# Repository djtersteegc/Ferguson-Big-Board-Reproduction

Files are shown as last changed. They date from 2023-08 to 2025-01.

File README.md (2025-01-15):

# Ferguson Big Board Reproduction

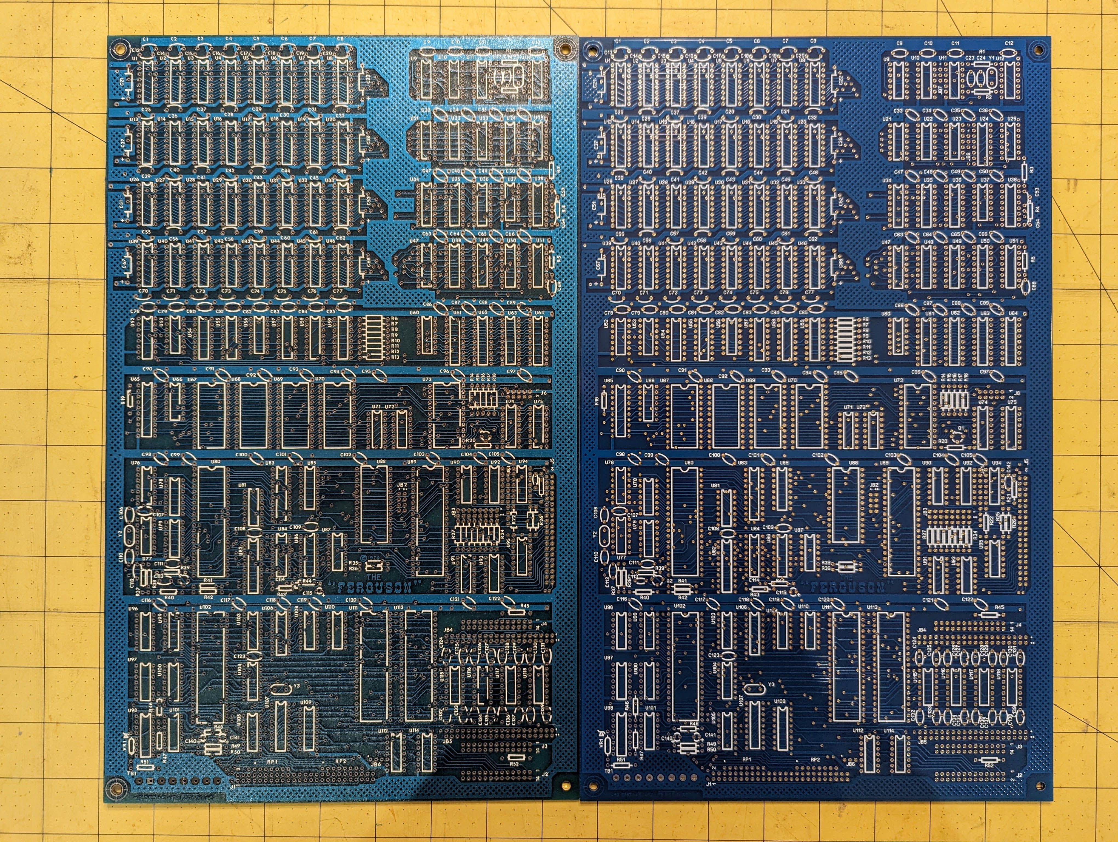
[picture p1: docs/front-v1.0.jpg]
front


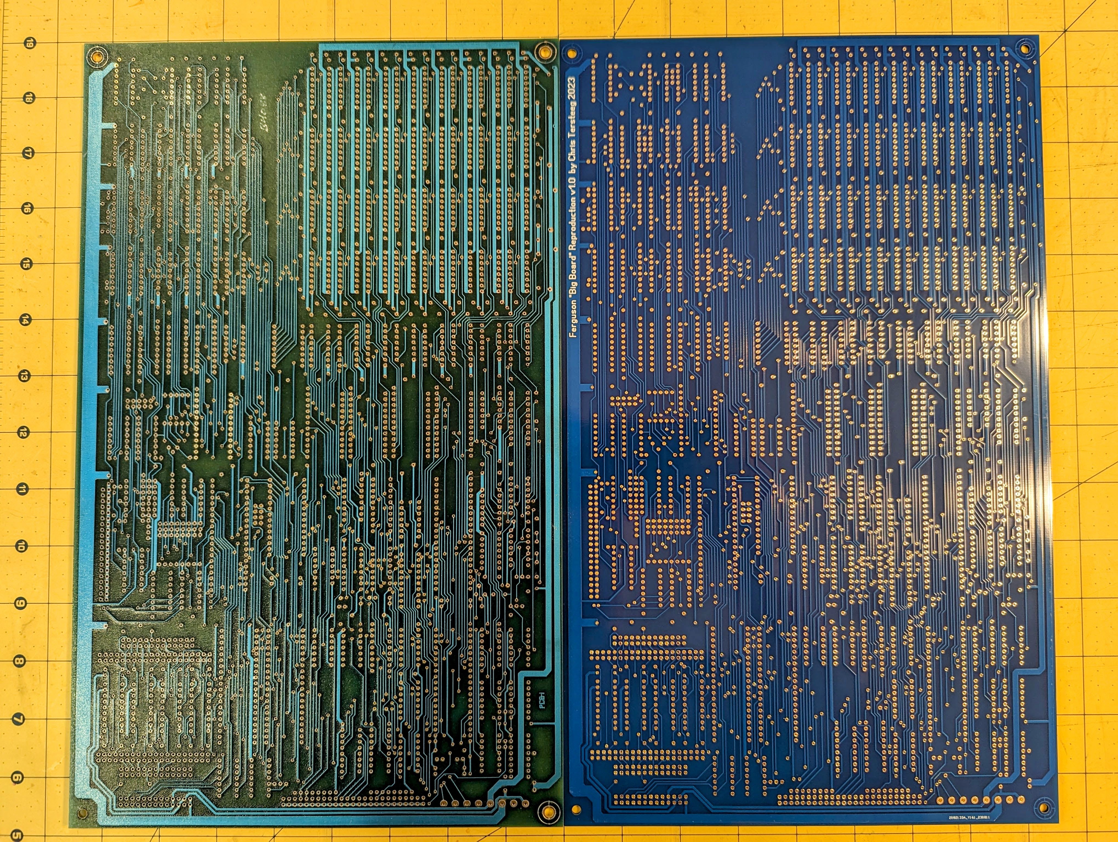
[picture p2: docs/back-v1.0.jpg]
back


Original is on the left above, the repoduction is on the right. Redraw in Sprint Layout from scans of an unpopulated board, serial number B4088.  Project discussion thread on VCF is at https://forum.vcfed.org/index.php?threads/recreating-the-ferguson-big-board.68349/ 

Mostly original with the following changes present on v1.0 and v1.1 boards:

Silkscreen of U52 corrected from a DIP-16 to DIP-14 socket.

Silkscreen reference Q1 added

Silkscreen reference Q2 added

Silkscreen reference R21 added

Silkscreen reference C142 added

Added missing vias for the top two memory bank -5V traces

Pin 14 silkscreen reference on J2 (keyboard connector) corrected to read pin 2

Jumper JB7 added to switch line character count between 97 and 128.  Strap middle pin to top pin to connect U11 pin 3 to +5V for 128 counts. Strap middle pin to bottom pin to connect U11 pin 3 to U10 pin 2 for 97 counts. *Micro Cornucopia, Number 10, February 1983, page 32*

Jumper JB8 added to switch between 7 and 8 dot character widths. Strap middle pin to top pin to connect U24 pin 3 to +5V for 7 dots. Strap middle pin to bottom pin to connect U24 pin 3 to GND for 8 dots. *Micro Cornucopia, Number 10, February 1983, page 32*

### Original Schematic Errata

**Sheet 4 - Floppy, Keyboard PIO, CTC**

IORQ input on U111 (PIO) should be pin 36, not pin 34

Connector J1-6 (Low Current) connects to resistor network pin RN1-2, not RN1-3.

Resistor networks RN1 and RN2 are labeled RP1 and RP2 respectively on the PCB silkscreen

The output from U87 pin 4 that controls the two 74LS242 buffers, U99 and U100, does not go though U103 and instead hooks directly to the 74LS242 chips.  This makes sense since you need a high signal to the buffers to read data from the FD1771 which U87 (NOR) outputs when both 1771CS and RDB are asserted active low.

##### Sheet 5 - GP PIO/SIO

BAUDA and BAUDB are reversed, U107 (8116) Pin 12 is BAUDB, U107 (8116) Pin 8 is BAUDA

### **V1.0 PCB Errata**

Like the original board, VPP on the Character Set EPROM (U73, pin 21) is unconnected and needs to be wired to +5V (U73, pin 24) for normal operation.

C114 pads have the footprint of vias and no symbol on the silkscreen layer.  Same as the original, but could be improved.

Right pad R40 unconnected, should be connected on bottom copper to the base of Q2 above it.

Top pad of R25 unconnected, should be connected on top copper to top pad of R26.

Pins 4 and 5 at U77 unconnected, should be connected on bottom copper.

Pins 19 and 20 on U65 unconnected, should be connected on bottom copper.

RP2-6 and J1-42 are unconnected, should be connected on bottom copper.

RP1-2 and J1-6 are unconnected, should be connected on top copper.

U81 pin 1 should be connected on top copper to the via immedately to it's right which goes to U84 pin 5. 

U22 pin 8 should be connected to the trace running immediately above it to connect to U9 pin 11 and U25 pin 5.  There is a via under U21by pin 9 that can complete this connection.

U37 pin 6 should be connected to trace running immediately below it to connect to U38 pin 10 and U10 pin 5. A bodge between U37-6 and U38-10 is the most direct.

U35 pin 1 should be connected to the +5V rail immediately above it.

### **V1.1 PCB**

All the V1.0 errata has been fixed and some additional features dicussed below added.  The goal was still to try to maintain a stock appearance from the topside, so the additional frequency selection and power to floppy disk port jumpers are all on the back side of the board.

#### 4 MHz Operation

One of the popular mods was reaplacing the Z80 with Z80A and increasing the frequency from 2.5 MHz to 4 MHz.  There were several ways to do this, but v1.1 implements the ability to easily do the mod discussed in Micro Cornucopia issue #3 (which is what Kaypro also adopted in their designs) with solder jumpers on the back of the board.  No trace cutting or bodge wires needed.

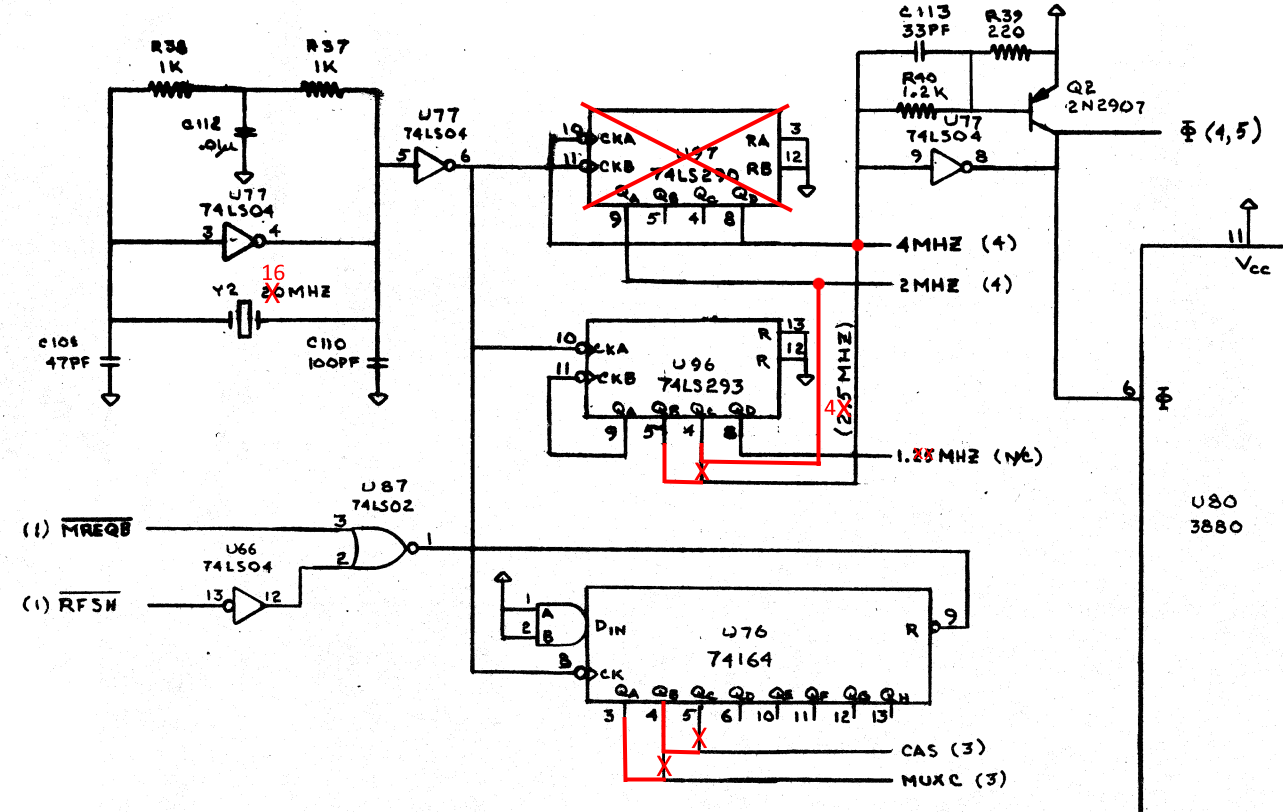
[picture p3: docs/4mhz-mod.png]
4mhz-mod


For stock 2.5 MHZ operation you need to install all the IC's per the BOM and use a 20 MHz crystal for Y2.  Then close the following three solder jumpers.

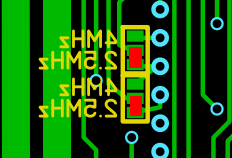
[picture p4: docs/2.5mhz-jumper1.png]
2.5mhz-jumper1


2.5mhz-jumper2

For 4 MHZ operation do NOT install U97 and use a 16 MHz crystal for Y2.  Then close the following five solder jumpers.

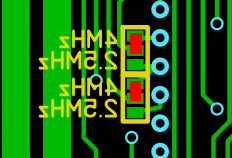
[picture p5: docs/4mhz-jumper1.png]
4mhz-jumper1


4mhz-jumper2

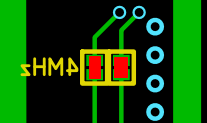
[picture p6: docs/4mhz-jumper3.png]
4mhz-jumper3


#### Fully Compensated Video Output

Another Micro Cornucopia article in issue #14 discussing swapping the 74LS123's in the video output circuit with 74LS221's that are both voltage and temperature compensated in an effort to improve video output jitter.

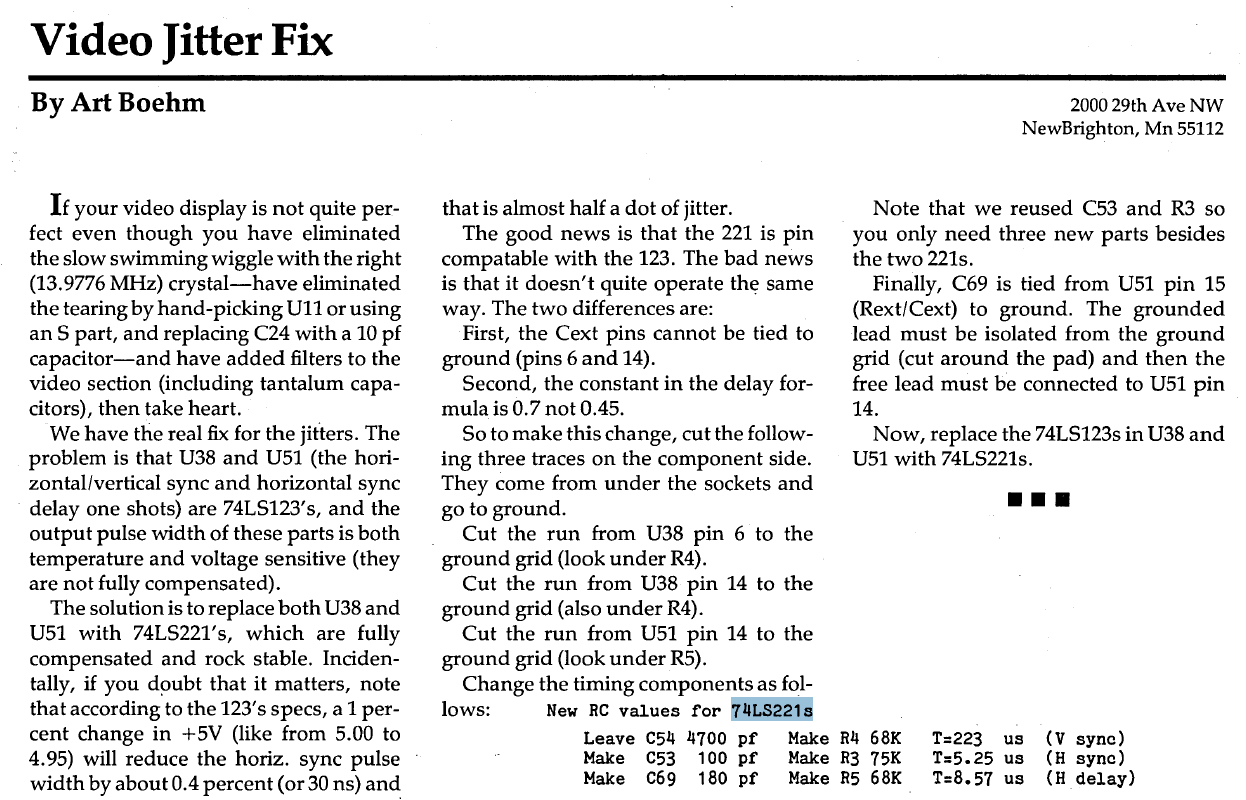
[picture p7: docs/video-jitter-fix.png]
video-jitter-fix


v1.1 already disconnects the appropiate pins on U38 and U51 from ground so all you need to do is use the updated values for C53, C69, R4, R3, and R5.

#### Additional Tantalum Capacitor Locations

Many Micro Cornucopia articles discussed bodging some additional tantalum caps to the video output section to improve quality.  While not labeled on the board to keep it more original looking, there are extra spots now to add them if you want to experiment.  Someone like a 22uF 10V (or higher) cap it probably a good start.

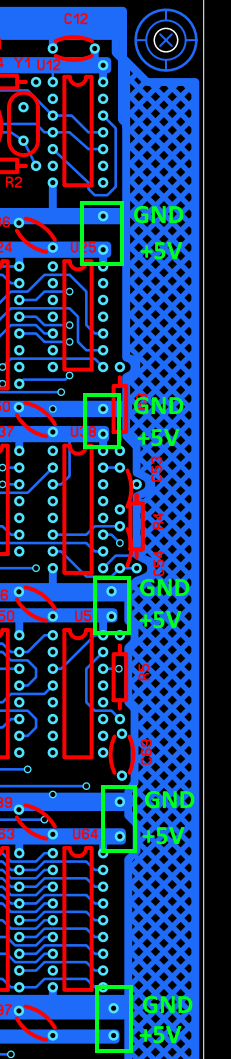
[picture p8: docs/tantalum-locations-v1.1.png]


### Serial Keyboard Adapter

I also created a PS/2 to parallel keyboard adapter PCB that should plug right into the Big Board based on the work shared here, https://forum.vcfed.org/index.php?threads/ferguson-big-board-1-monitor-rom.32705/#post-405189.  It's available at https://github.com/djtersteegc/ferguson-ps2-keyboard-adapter

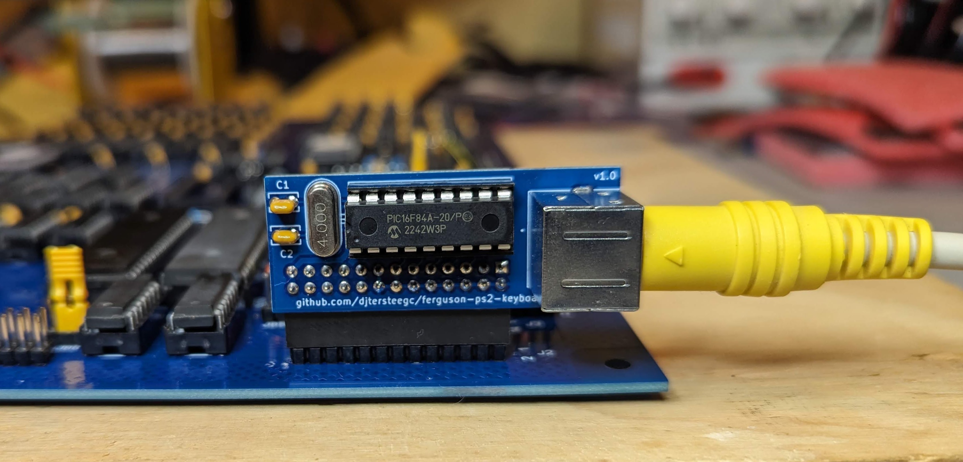
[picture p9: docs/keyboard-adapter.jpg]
keyboard-adapter


Strap JB6 center to right pad to set negative strobe.

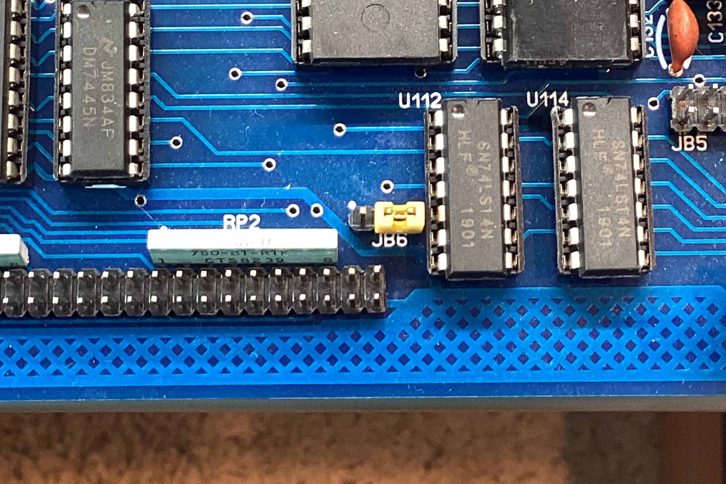
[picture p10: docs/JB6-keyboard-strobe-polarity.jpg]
JB6-keyboard-strobe-polarity


### Power

The manual calls for the following:

+5V at 3 amps

+12V at 0.25 amps

-12V at 0.20 amps

Either a Mean Well RT-50B (5V@4A) or RT-65B (5V@5A) will do the job. I chose the slighty larger RT-65B since it was only a few bucks more. 3D printable case designs for both that also incorporate the reset button are available in the [psu](psu/README.md) directory.

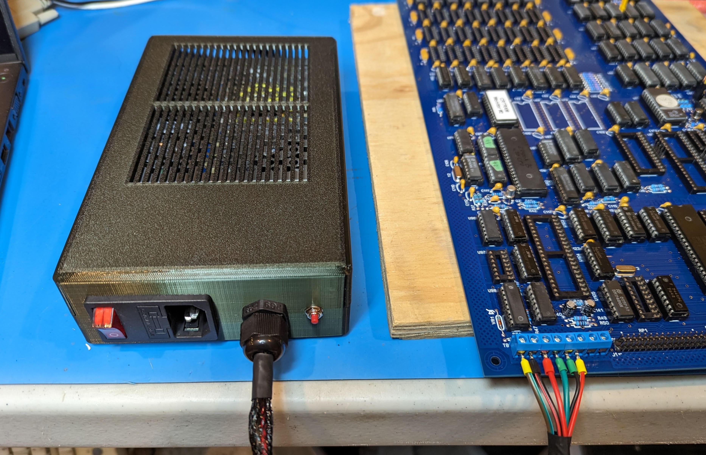
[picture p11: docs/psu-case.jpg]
psu-case


### Composite Video Output

On JB1 connect pins 10 and 11, pins 3 and 4, and pins 5 and 6.

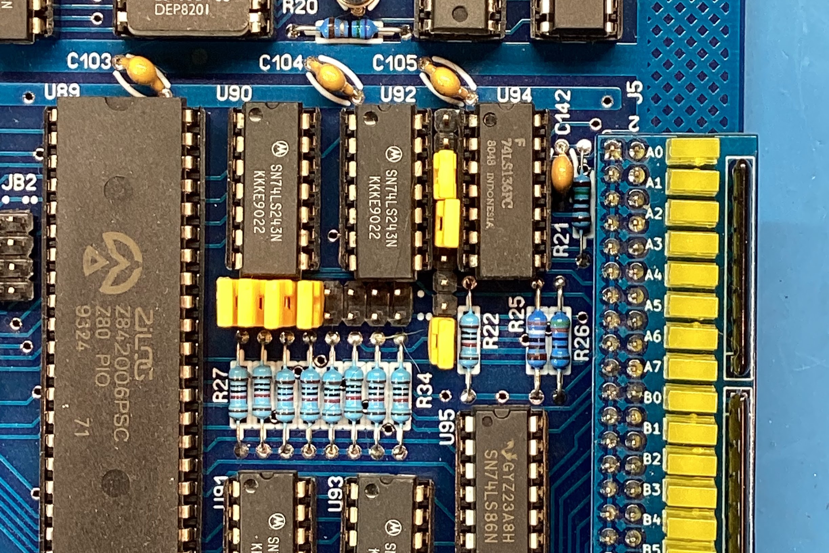
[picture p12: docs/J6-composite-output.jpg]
J6-composite-output


This routes both the v.sync and h.sync signals to the composite output, and inverts the video (white on black). Then build a cable using something like a Dupont two pin 2.54mm connector and connect you ground to pin 9 and signal to pin 10 on connector J6.

If you want to make a fancy composite video adapter PCB, head over to the [composite-video-adapter](composite-video-adapter/README.md) directory.

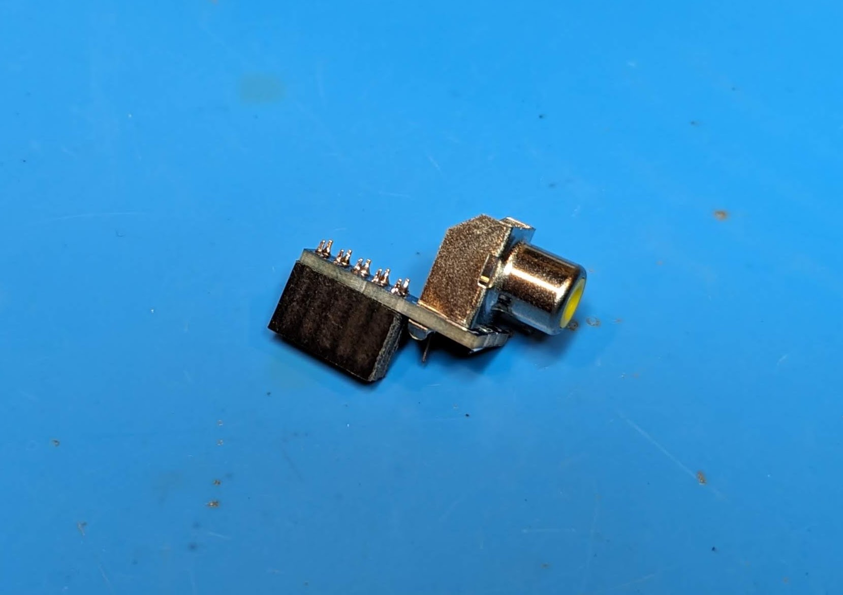
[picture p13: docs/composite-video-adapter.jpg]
composite-video-adapter


Jumper JB7 and JB8 were not on the original boards, but added to implement the following video display options/improvements mentioned in *Micro Cornucopia, Number 10, February 1983, page 32*

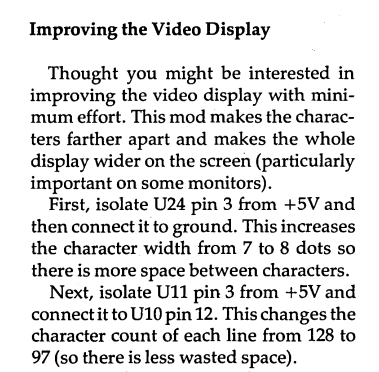
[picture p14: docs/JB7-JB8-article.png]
JB7-JB8-article


Jumper JB7 switches line character count between 97 and 128.  Strap middle pin to top pin to connect U11 pin 3 to +5V for 128 counts. Strap middle pin to bottom pin to connect U11 pin 3 to U10 pin 2 for 97 counts.

Jumper JB8 switches between 7 and 8 dot character widths. Strap middle pin to top pin to connect U24 pin 3 to +5V for 7 dots. Strap middle pin to bottom pin to connect U24 pin 3 to GND for 8 dots.

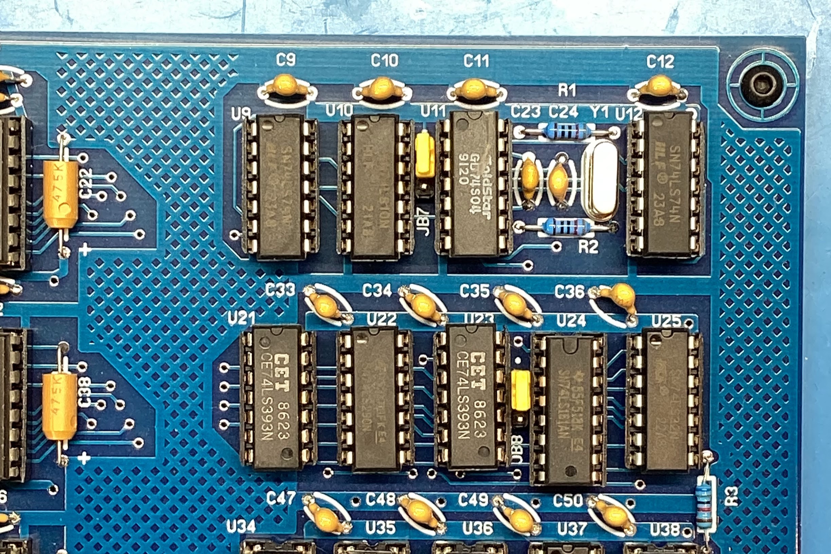
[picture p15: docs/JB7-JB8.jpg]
JB7-JB8


### Serial Terminal

Instead of a keyboard and monitor, you can also operate the BigBoard via a serial termainl connected to the B channel connector J3.  For a DB9 male DTE cable wire accordingly, I used a three pin Dupont connector.  

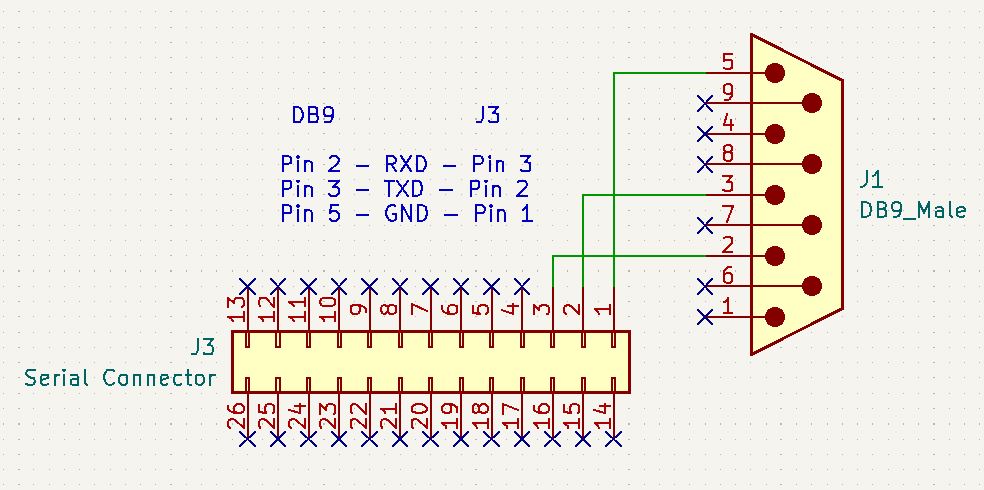
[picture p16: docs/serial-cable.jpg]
serial-cable
  

On JB5 jumper pins 5 and 6, and pins 9 and 10.

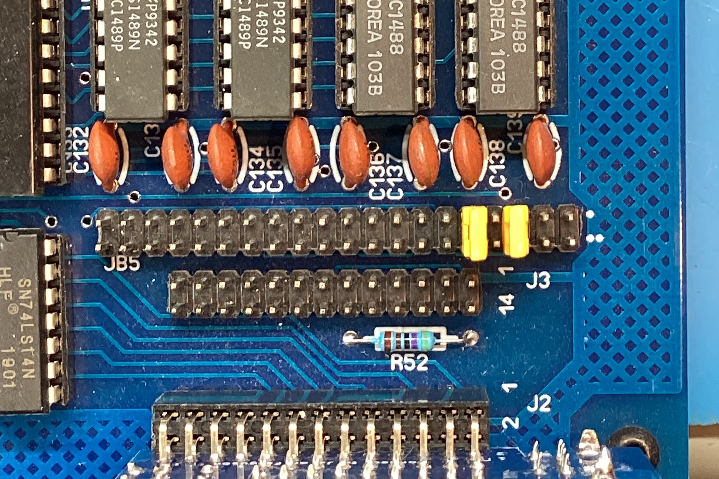
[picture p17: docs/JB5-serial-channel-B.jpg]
JB5-serial-channel-B


You will need to use a null modem cable to connect to your terminal device, or PC USB adapter running something like Terraterm.

The port will autobaud when you hit the return key, up to 19.2K.  I run the terminal set to 19,200 baud, 7 bit, odd parity, 1 stop bits, with no flow control.  When you startup or reset the big board, the first device, keyboard or serial terminal, that sends a return character will become the input and output device for the board.

### Floppy Drive

A number of disk image compatible with a Flash Floppy converted Gotek are available in the [flashfloppy](flashfloppy) directory.  Copy the content of the directoy to a USB stick and make sure you are using an up to date version of the Flash Floppy firmware.

To convert the 50 pin drive connector to a 34 pin floppy drive, you can build the adapter in the [50-to-34-pin-floppy-adapter](50-to-34-pin-floppy-adapter/README.md) directory.

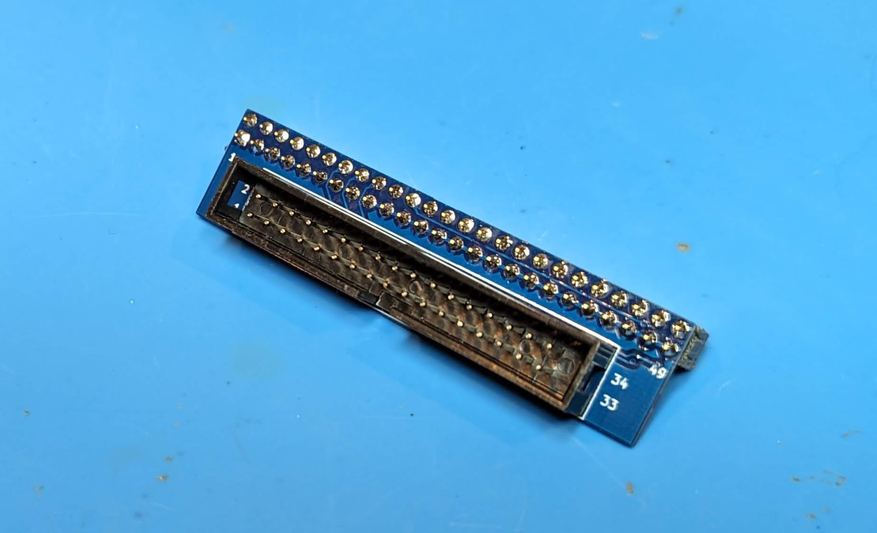
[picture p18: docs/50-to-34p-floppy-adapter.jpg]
50-to-34p-floppy-adapter


The general purpose 50 to 34 pin adapter available at https://github.com/pski/fd50to34 has also been tested and works well.

If you are feeling extra industriuous, you can build my custom FlashFloppy compatible board the plugs directly into the Big Board's floppy board, no extra cabling needed.  Details at https://github.com/djtersteegc/OpenFlops-Ferguson

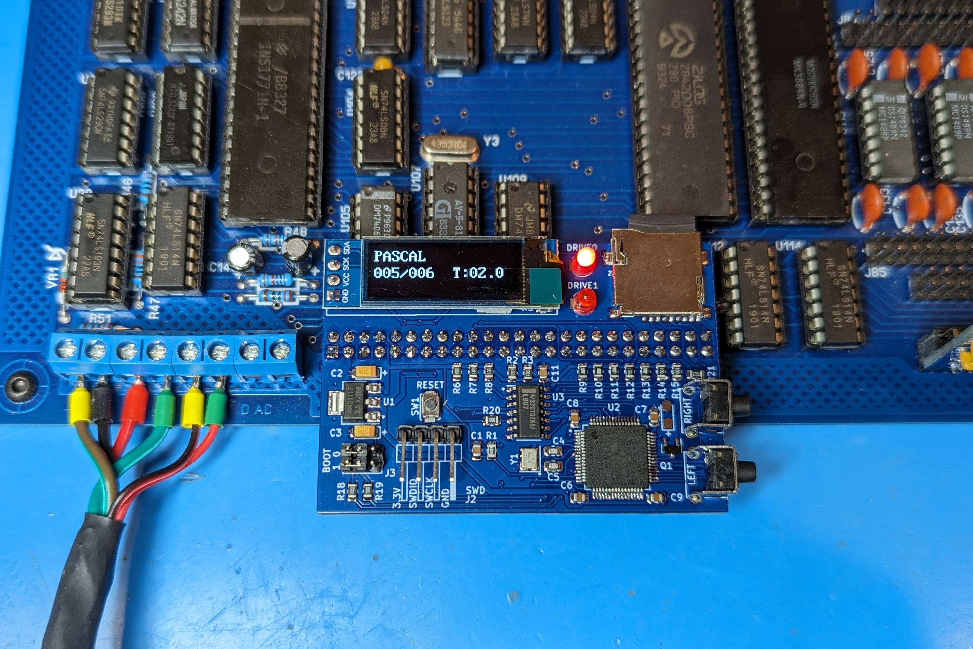
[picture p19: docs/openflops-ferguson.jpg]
openflops-ferguson


### PIO Port and Blinken LED's

What good is an extra PIO port without something for it to do?  Build yourself a sixteen [LED blinken board](pio-port-blinkenlights/README.md) and make it dance.

[https://youtu.be/wRvbjzvjgtw](https://youtu.be/wRvbjzvjgtw)

https://youtu.be/wRvbjzvjgtw

Make sure to strap pins 9 and 10, 11 and 12, 13 and 14, and 15 and 16 on JB4 to set all the PIO port bits to ouputs.

J6-composite-output

### **Other Links**

Original manuals and schematics  on BitSaver - http://www.bitsavers.org/pdf/ferguson/Big_Board_1980.pdf 

The Micro Cornucopia magazine archive is also available - http://www.bitsavers.org/magazines/Micro_Cornucopia/ 

Enrico's excellent collection of information and other links - https://www.vintagesbc.it/vintage-computer-board/collezione/ferguson-big-board-i/

ShadowTron's YouTube series on restoring an original board - https://www.youtube.com/watch?v=K9SL5NfVGII&list=PLAvOjNk-JGgWwtCWdAmB9IXlpt3gtpXcv&ab_channel=ShadowTronBlog  He also has additional docmentation in his repo at https://github.com/nbreeden2/FergusonBigBoard

### **Building Tips**

An updated BOM is available at https://docs.google.com/spreadsheets/d/1wBH6rk6youMYVbVZ4vIVZXSmrotHBEZvTTkY6PEE75M/edit?usp=sharing  The one in the manual is missing some components and has the incorrect value for the video crystal. 13.9776 mHz crystals are pretty much unobtanium these days, but 13.97734 MHz ones are still availbe in two different flavors on [LCSC](https://www.lcsc.com/products/Crystals_537.html).  Otherwise a 14 MHz version is a better choice than the stock 14.31818 MHz value.

Most of the capacitors have a 6.35mm lead spacing, 3D printable lead forming tools are available in the **tools** directory of this repo for modifying the more standard (these days) 5.08mm spacing of generic MLCC caps.  There is also a bender for the axial tantalums.

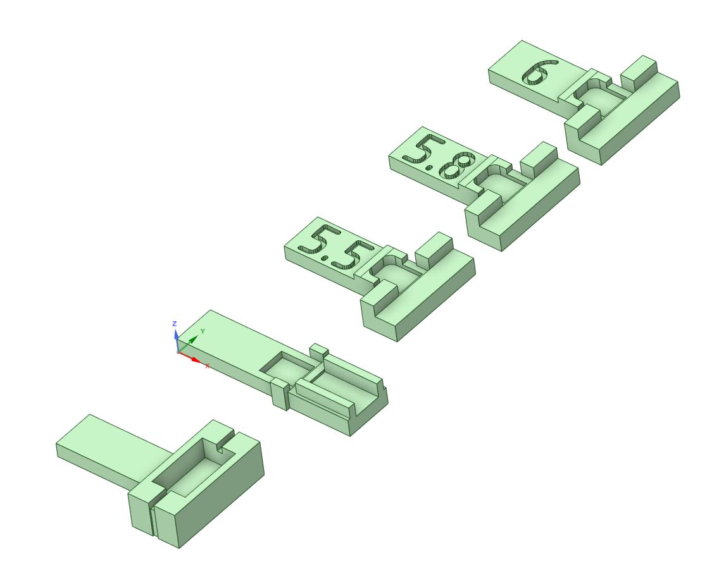
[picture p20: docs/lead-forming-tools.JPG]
lead-forming-tools


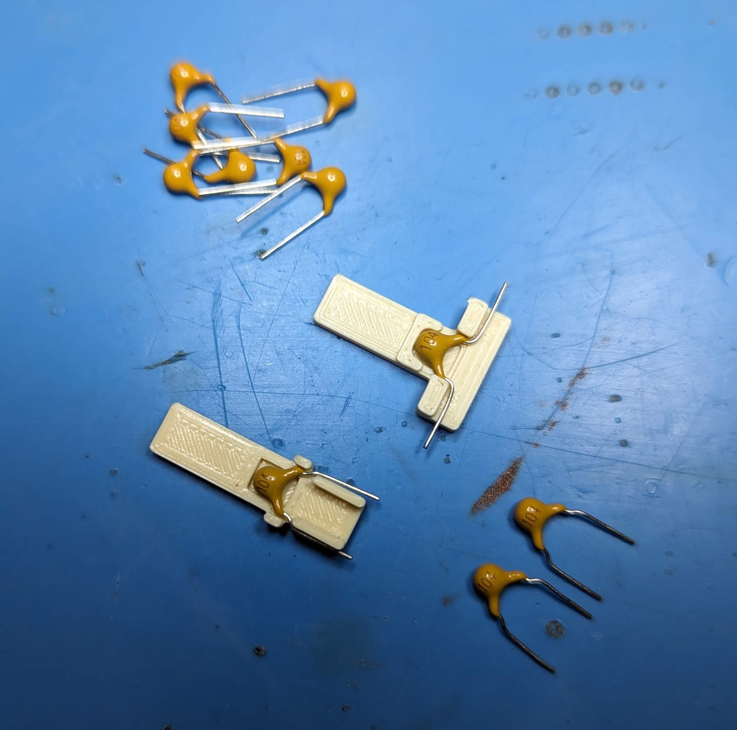
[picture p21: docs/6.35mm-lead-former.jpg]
6.35mm-lead-former


There is likely going to be a bit of a bend in a PCB of this size, so make sure your sockets are tight to the board before soldering them down.  I find it's quicker to tack one leg, flip the board, and then use your finger to **gently** push the socket down while reheating the single solder joint.  You can also tape/blue tack the sockets before soldering (takes longer) or buy the fancy sockets that snap into the board but that will get really expensive give the component count here.

The single row jumpers JP1, JP7, and JP8 are tight between the adjacent sockets, so make sure they fit before you completely solder the IC sockets down.

The resistor networks RP1 and RP2 and are also tight against the 50 pin disk connector J1, so I installed a cable first to confirm clearance and then angled the networks back a bit before soldering them in.

The silkscreen on the board for Q1 and Q2 assume you are using metal cased TO-18 style transistors with the little tab.  If using the more common plastic cased TO-92 transistors, make sure the flat side of the case is facing towards the power connector end of the board.

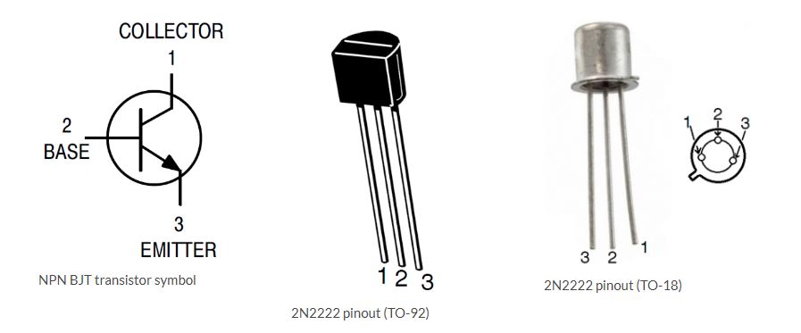
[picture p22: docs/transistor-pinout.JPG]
transistor-pinout


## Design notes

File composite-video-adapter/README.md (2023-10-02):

If you don't want to make your own composite cable.

composite-video-adapter

### BOM

The composite jack is one of standard AliExpress models, often called [AV-103B](https://www.aliexpress.us/item/3256803528316207.html).  Similar to a CUI Devices RCJ-014.

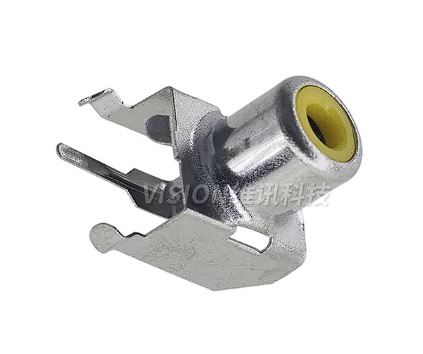
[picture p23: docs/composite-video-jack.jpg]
composite-video-jack


2x5p 2.54mm double row female pin header socket.  I buy the [2x40P](https://www.aliexpress.us/item/2251832703602124.html) models and cut them down (it's cheaper), and you need them for the keyboard, floppy, and blinken board PCB's.

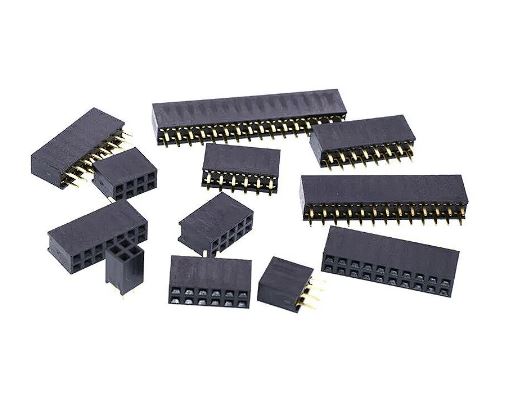
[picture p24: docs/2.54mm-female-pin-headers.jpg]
2.54mm-female-pin-headers


### Assembly

Should be self explanatory. I soldered the 2x5 IDC socket first, followed by the jack.

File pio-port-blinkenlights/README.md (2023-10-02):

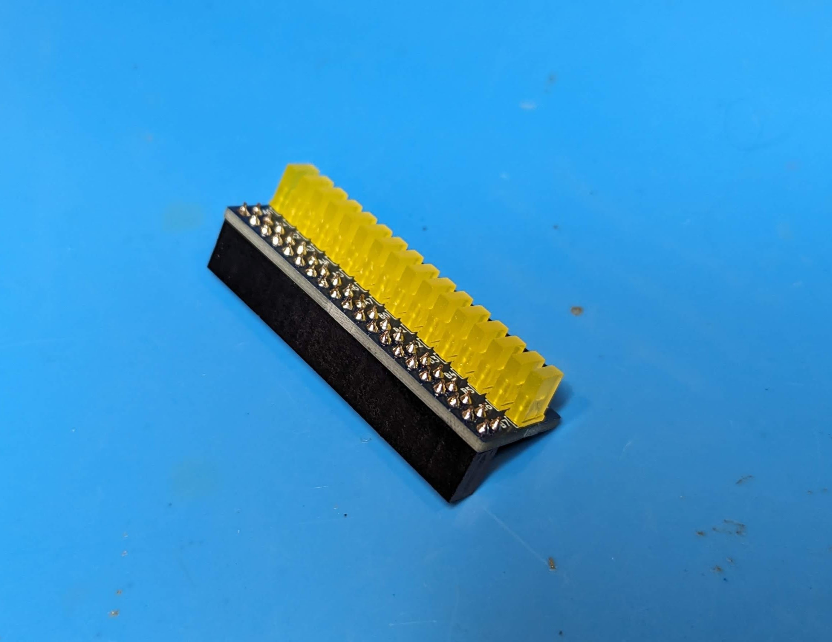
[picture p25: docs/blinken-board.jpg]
blinken-board


### BOM

| Part | Qty  | Source |
| --- | ---- | --- |
| 2x20 40pin 2.54mm Female Straight Pin Header | 1 | [Aliexpress](https://www.aliexpress.us/item/3256801594858362.html) |
| 2 x 5 x 7mm LED (pick your favorite color) | 16 | [Aliexpress](https://www.aliexpress.us/item/2255800718649696.html) |
| 9 pin 470R Resistor Network Array | 2 | [Aliexpress](https://www.aliexpress.us/item/2251832653789055.html) |

### Assembly

If you have a 3D printer, print the assembly jig, and plug in all the LED's observing polarity.  I cut them all down, except for one, to ease with insertion into the PCB.

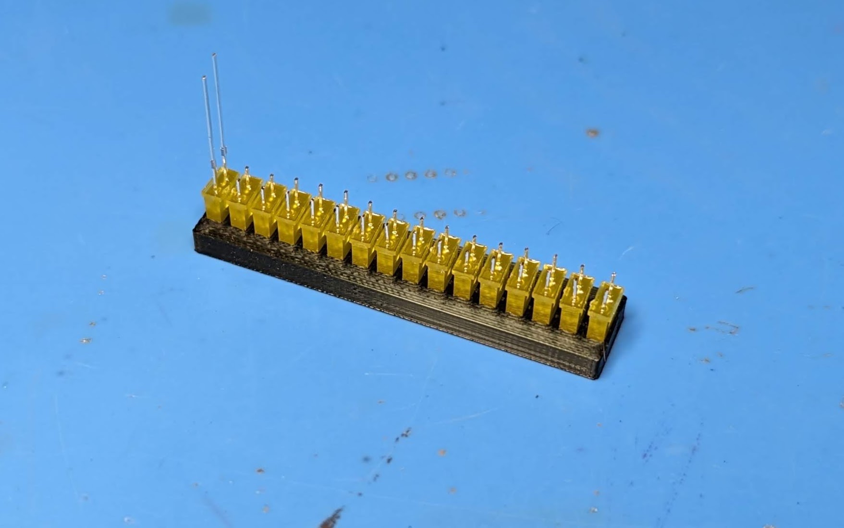
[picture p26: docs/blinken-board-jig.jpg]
blinken-board-jig


Pin one on the resistor array's both point towards the middle of the PCB.

### Software

On the PASCAL.img disk there a various blinken programs and exectutables written in Turbo Pascal 3.0a.

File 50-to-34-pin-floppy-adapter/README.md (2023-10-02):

Slimmed down version of https://github.com/pski/fd50to34.  For the Big Board you do NOT need to close any of the solder jumpers on the back.

### BOM

| Part | Source |
| --- | --- |
| 2x25 50pin 2.54mm Female Straight Pin Header | [Aliexpress](https://www.aliexpress.us/item/3256801594858362.html) |
| 2x17 34pin 2.54mm Male Straight Box Socket | [Aliexpress](https://www.aliexpress.us/item/2251832660396046.html) |

### Assembly

I soldered the female header, then the box socket.  If you buy extra parts, you can use them to support the other side of the board to make it level.

50-to-34p-floppy-adapter

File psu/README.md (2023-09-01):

First off, credit to [mozzwald](https://mozzwald.com/) who designed the [original version](https://www.thingiverse.com/thing:5178605) of this case around an RT-50 PSU for the Coleco ADAM community.  All I did was add the reset button and stretched it a bit for the larger RT-65 version.  Print both the top and bottom of the case face down. I used supports on the button only for the IEC, cable, and button openings.  20% infill should be fine.  All the parts other than the PSU came from AliExpress shops, but you can also find these parts on Amazon or the usual electronic suppliers if you want slightly nicer (and more expensive) versions of everything.

### BOM

[IEC Inlet](https://www.aliexpress.us/item/3256802824106295.html) I used one with a lighted switch, but it turned out to be neutral switched (China, why?) instead of the line switched so caveat emporium.  Lots of different options in this form factor.

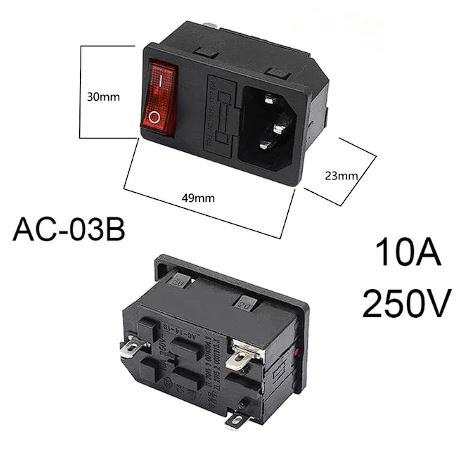
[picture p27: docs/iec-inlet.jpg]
ice-inlet


[5mm Momentary Switch](https://www.aliexpress.us/item/2255799950576497.html)

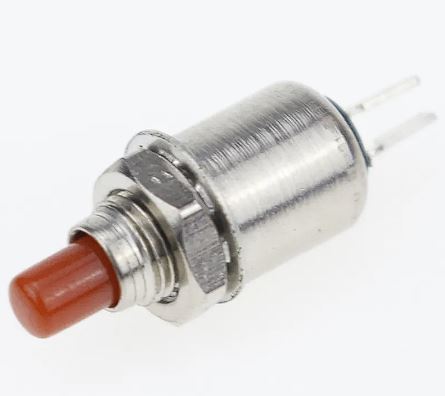
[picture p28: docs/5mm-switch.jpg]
5mm-switch


[PG9 Size Cable Gland](https://www.aliexpress.us/item/2251832790063427.html)

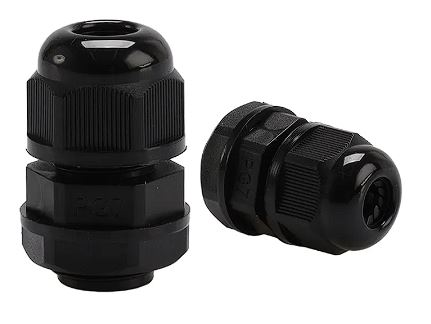
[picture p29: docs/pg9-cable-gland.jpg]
pg9-cable-gland


Two M3x6mm screws to hold down the PSU

Four M3x20mm or #4 x 1 inch screws to hold the case halves together

Whatever you want to use for wires, sheating, heatshrink, terminals, etc.

### Assembly

Should be self explanatory.  I ran the wires through the sheating/gland and then soldered the switch on after they were attached to the case.

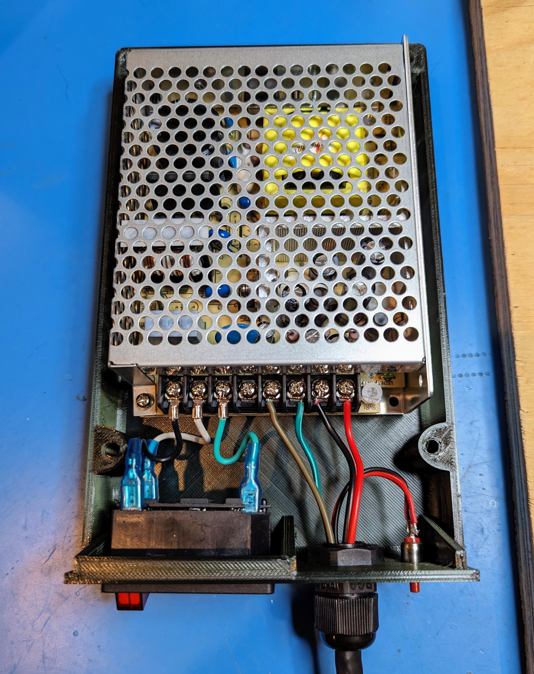
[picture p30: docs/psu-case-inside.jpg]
psu-case-inside


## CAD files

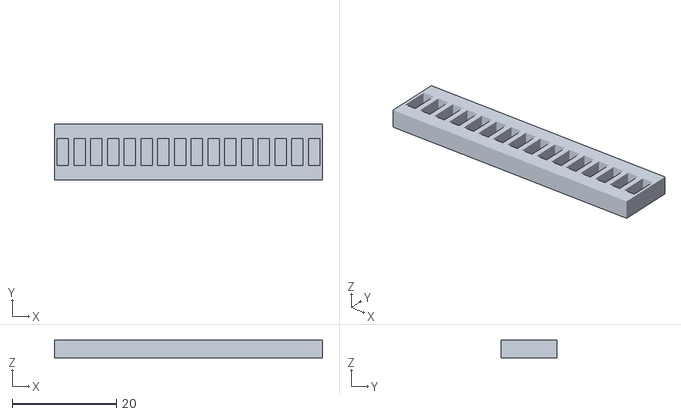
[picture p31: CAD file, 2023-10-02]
pio-port-blinkenlights/2x5mm 16 LED Jig.stl
51.5 x 10.8 x 3.40

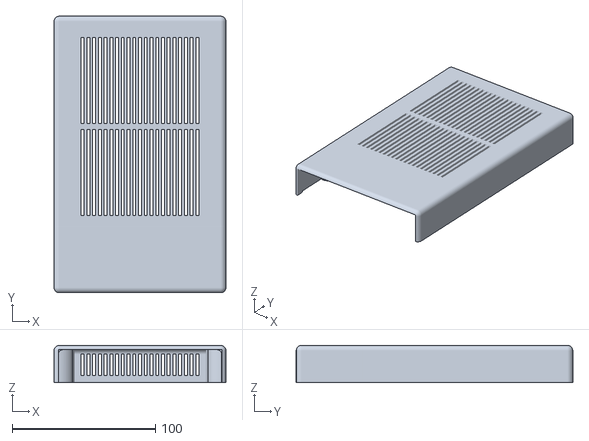
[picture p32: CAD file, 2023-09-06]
psu/Mean Well RT-65B Power Supply Case Top.stl
120.0 x 193.0 x 26.0

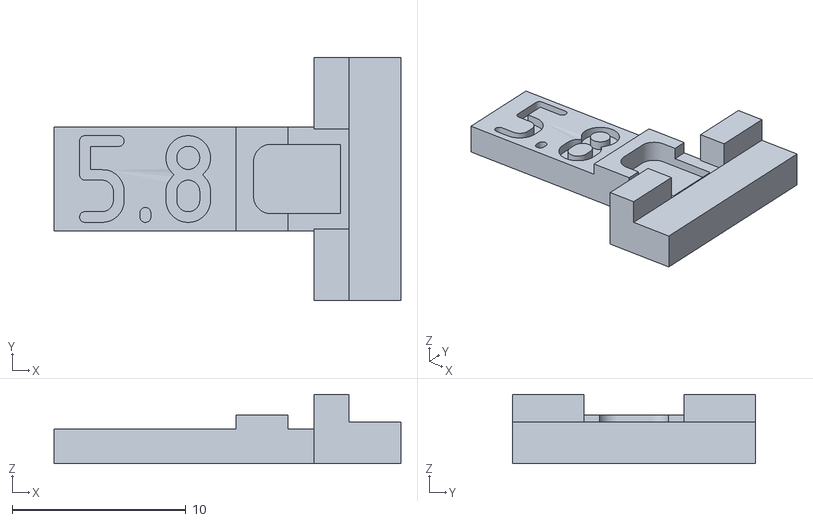
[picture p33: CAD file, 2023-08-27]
tools/6.35mm Lead Bender v2 5.75mm Wide - Step 1.stl
20.0 x 14.0 x 4.00

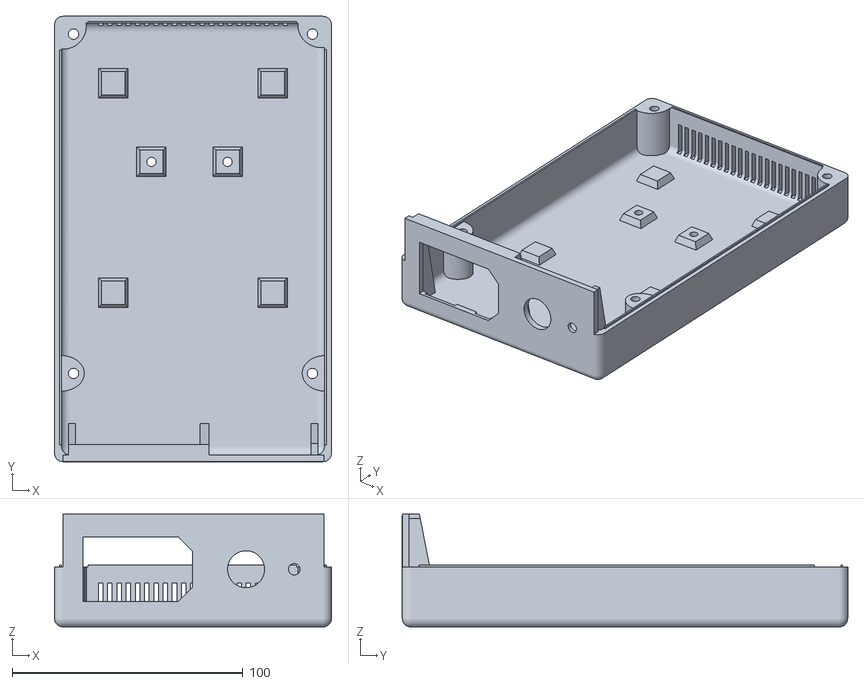
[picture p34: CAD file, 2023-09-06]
psu/Mean Well RT-65B Power Supply Case Bottom.stl
120.0 x 193.0 x 48.9

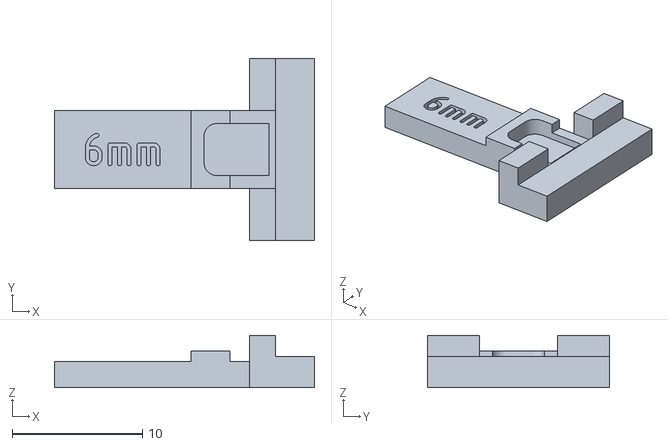
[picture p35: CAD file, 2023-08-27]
tools/6.35mm Lead Bender v2 6mm Wide - Step 1.stl
20.0 x 14.0 x 4.00

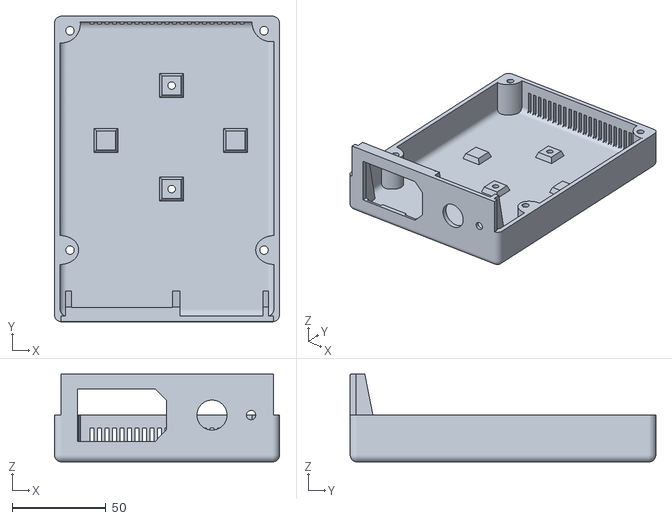
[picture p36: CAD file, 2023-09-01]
psu/Mean Well RT-50B Power Supply Case Bottom.stl
120.0 x 163.0 x 46.9

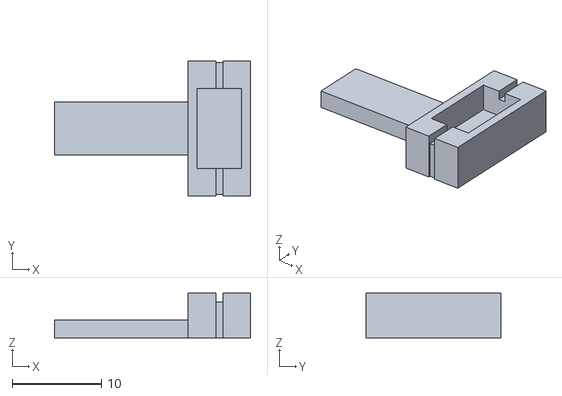
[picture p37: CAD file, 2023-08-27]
tools/15.4mm 9x5 Axial Tantalum.stl
22.0 x 15.2 x 5.00

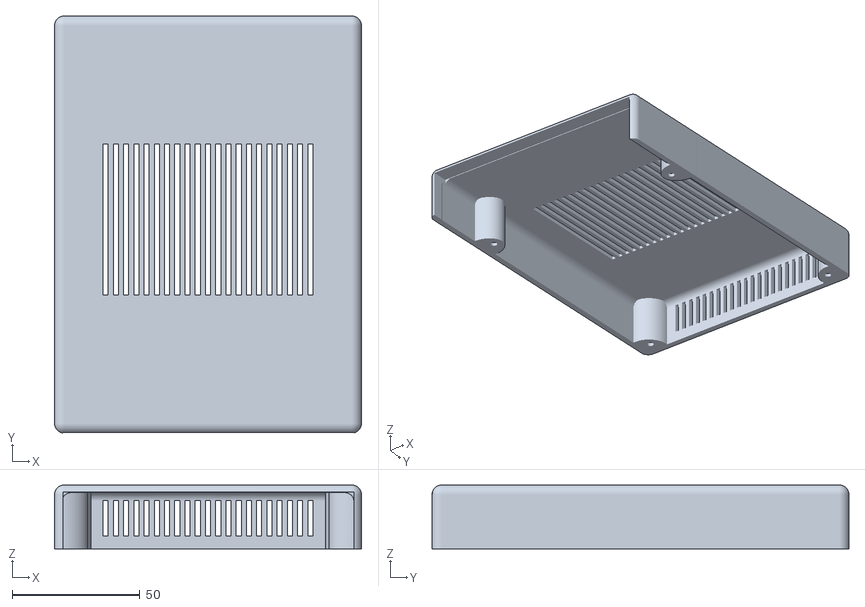
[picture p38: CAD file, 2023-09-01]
psu/Mean Well RT-50B Power Supply Case Top.stl
120.0 x 163.0 x 25.0

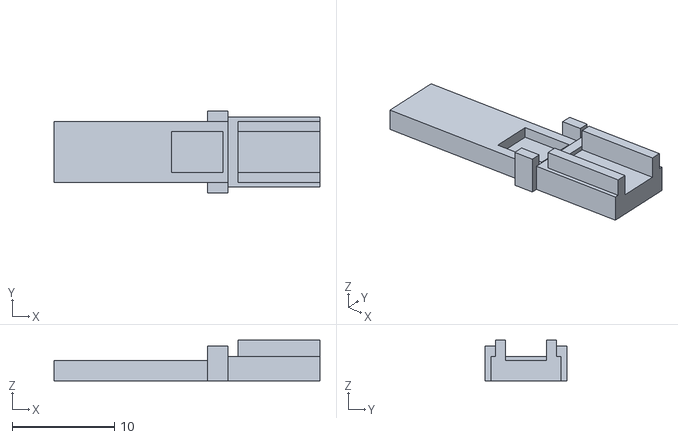
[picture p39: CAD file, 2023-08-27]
tools/6.35mm Lead Bender v2 - Step 2.stl
26.0 x 8.00 x 4.00

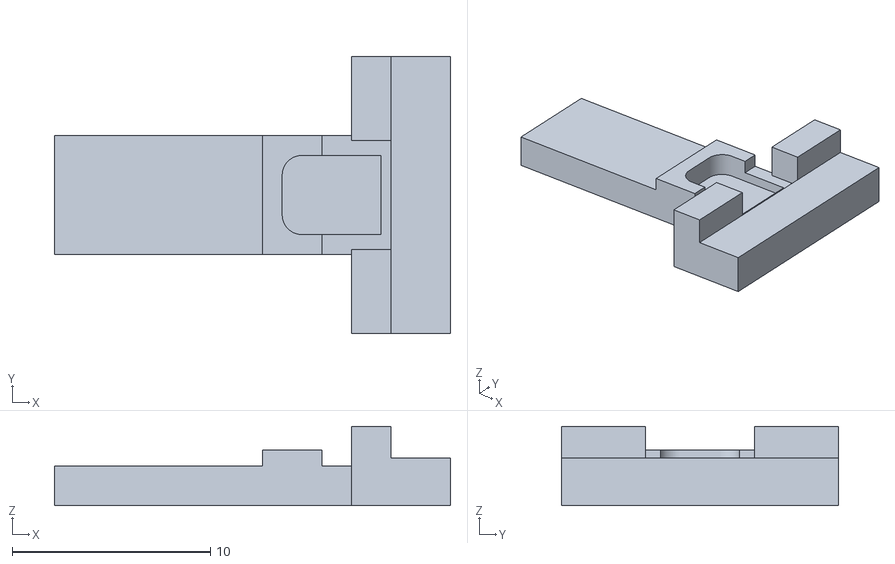
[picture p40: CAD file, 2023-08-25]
tools/6.35mm Lead Bender v2 - Step 1.stl
20.0 x 14.0 x 4.00

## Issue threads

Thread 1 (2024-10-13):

Update for v1.1?

ajacocks, 2024-10-13:
Hello, I picked up a v1.1 boardset from you, at VCF Midwest 2024. Have you had a chance to update the repo for v1.1, so I make sure that I build everything correctly?

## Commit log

2023-08-25 Add some docs
    [6.35mm Lead Bender v2 - Step 1.stl, 6.35mm Lead Bender v2 - Step 2.stl]
2023-08-27 Doc updates
    [15.4mm 9x5 Axial Tantalum.stl, 6.35mm Lead Bender v2 - Step 2.stl, 6.35mm Lead Bender v2 5.75mm Wide - Step 1.stl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]
2023-08-28 Another unconnected trace
2023-09-01 Add PSU case files and docs
    [Mean Well RT-50B Power Supply Case Bottom.stl, Mean Well RT-50B Power Supply Case Top.stl, Mean Well RT-65B Power Supply Case Bottom.stl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]
2023-09-02 Unconnected pin on U81
2023-09-02 Fix video scrolling, U35 pin 1 unconnected
2023-09-03 Fix README Errata, add Flashfloppy disk images and cfg
    [FF.CFG, IMG.CFG]
2023-09-06 Update docs Update RT-65B PSU case with lip Add CP/M Games disk image
    [Mean Well RT-65B Power Supply Case Bottom.stl, Mean Well RT-65B Power Supply Case Top.stl]
2023-10-02 Add additional accessory PCB's
    [2x5mm 16 LED Jig.stl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]
2023-10-02 Add README's for the accessory PCB's.
2025-02-28 Add additional Micro Cornucopia BIG BOARD USER DISK images
